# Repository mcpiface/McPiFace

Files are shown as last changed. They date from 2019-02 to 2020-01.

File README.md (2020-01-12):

# McPiFace

A Simple front panel for a raspberry pi to allow for blade style rack mounting.





## Version 1.1

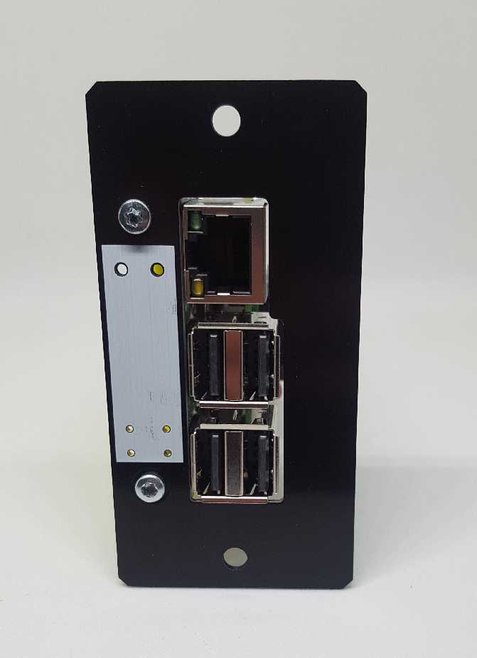
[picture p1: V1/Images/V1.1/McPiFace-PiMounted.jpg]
Pi Mounted


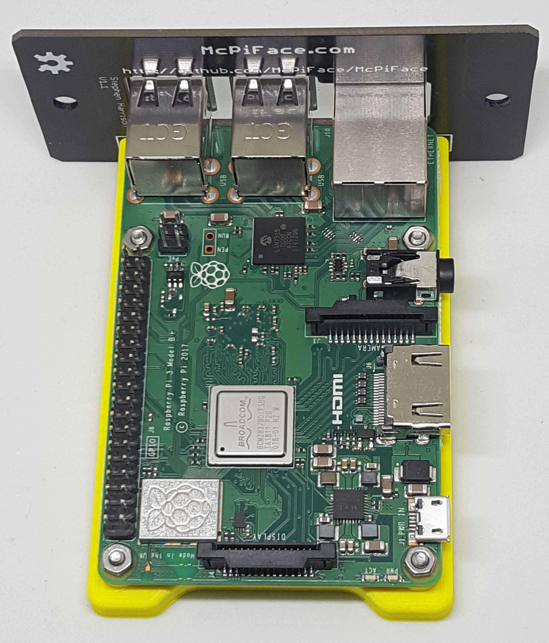
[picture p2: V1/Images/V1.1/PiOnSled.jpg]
Pi On Sled


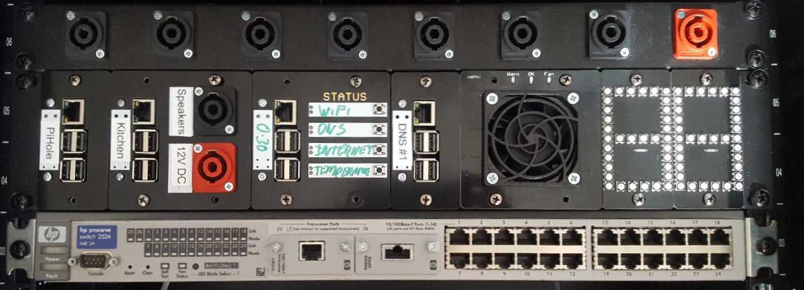
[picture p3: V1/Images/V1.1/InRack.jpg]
Various McPiFace's in a rack


## Connections

McPiFace has 2 LEDs (red/green) and a push button option. These can be ignored if not required.

Should you wish to use them, the examples assume the front panel connector is wired as follows: 

Black: Pin 39 GND
Red: Pin 40 (BCM 21)
Green: Pin 38 (BCM 20)
Blue (or Yellow): Pin 37 (BCM 26)

See https://pinout.xyz/ for Raspberry Pi header pinout.

## Python Code

The Examples folder contains sample Python code to interact with the LEDs and buttons.

The McPyFace.py script can be run to monitor the Pi's temperature and change the red/green LED when it gets hot, as well as shutdown or reboot the Pi when the button is pressed.

This file should be called from rc.local at startup. Instructions are given in the file to configure this and set permissions.

## Sled

To mount the raspberry Pi a 3D printable sled is available:

https://www.thingiverse.com/thing:3488157

## Rack Mount Frame

DAP Audio 2 HE Rackblende f. Modulsystem 10 Segmente MP-1 from Music Store.

* UK: https://www.dv247.com/en_GB/GBP/DAP-Audio-2-HE-Rackblende-f-Modulsystem-10-Segmente-MP-1/art-PAH0017160-000

* Germany: https://www.musicstore.de/en_US/USD/DAP-Audio-2-HE-Rackblende-f-Modulsystem-10-Segmente-MP-1/art-PAH0017160-000

## Version History

V1.0 - had Leds "hidden" in the vent grill and no button.
V1.1 - adopted common LED/button layout used across other McPiFace front panels.

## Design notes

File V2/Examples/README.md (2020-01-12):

# Example Python Scripts

The scripts in this folder are examples of how you might configure or use the LEDs and button on the McPiFace with a Raspberry Pi.

## Raspberry Pi Setup

The examples assume you've got python development environment installed on your Pi. Please follow http://raspberry.io/projects/view/reading-and-writing-from-gpio-ports-from-python/ if not.

## Connections

The samples assume the front panel connector is wired as follows: 

Black: Pin 39 GND
Red: Pin 40 (BCM 21)
Green: Pin 38 (BCM 20)
Blue (or Yellow): Pin 37 (BCM 26)

See https://pinout.xyz/ for Raspberry Pi header pinout.

## Simple.py

This example reads the button input, lights the green then red LEDs, switches off the LEDs and reads the button a second time.

## ButtonCallback.py

Demonstrates using a callback function to handle the button

## WaitForButton

Demonstrates reading the button status.

## McPiFace.py

This is the main script to run for the McPiFace LED/buttons. 

It will set the LEDs to red/green based on the Pi's temperature. Going red at 80C. Change:

pi_temperature_warning = 80

to a different value to change the LED indication.

Pressing the button will cause the Pi to shutdown. Swap the comment # over to switch between shutdown and reboot.

os.system('sudo shutdown now') # shutdown
#os.system('sudo shutdown -r now') # reboot

## Other examples:

### On Off switch from The Mag Pi Magazine 

Note the switch is wired to GPIO 21, not 26 as used by McPiFace, so you'll need to change the code.

https://www.raspberrypi.org/magpi/off-switch-raspberry-pi/

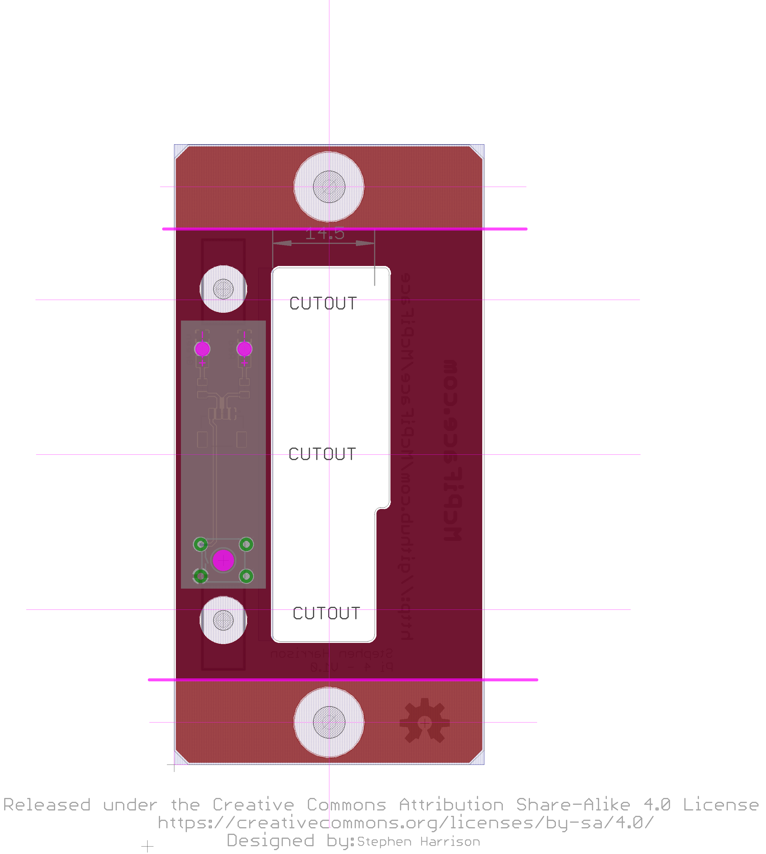
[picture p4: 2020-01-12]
V2/Images/PcbAllLayersDesign.png

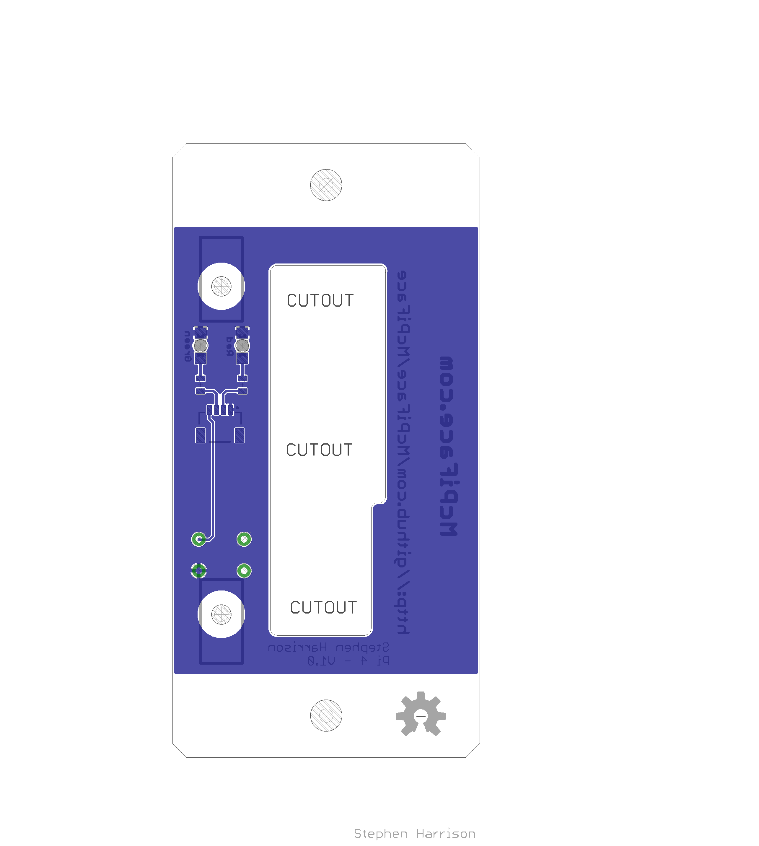
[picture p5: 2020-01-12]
V2/Images/PcbBottomDesign.png

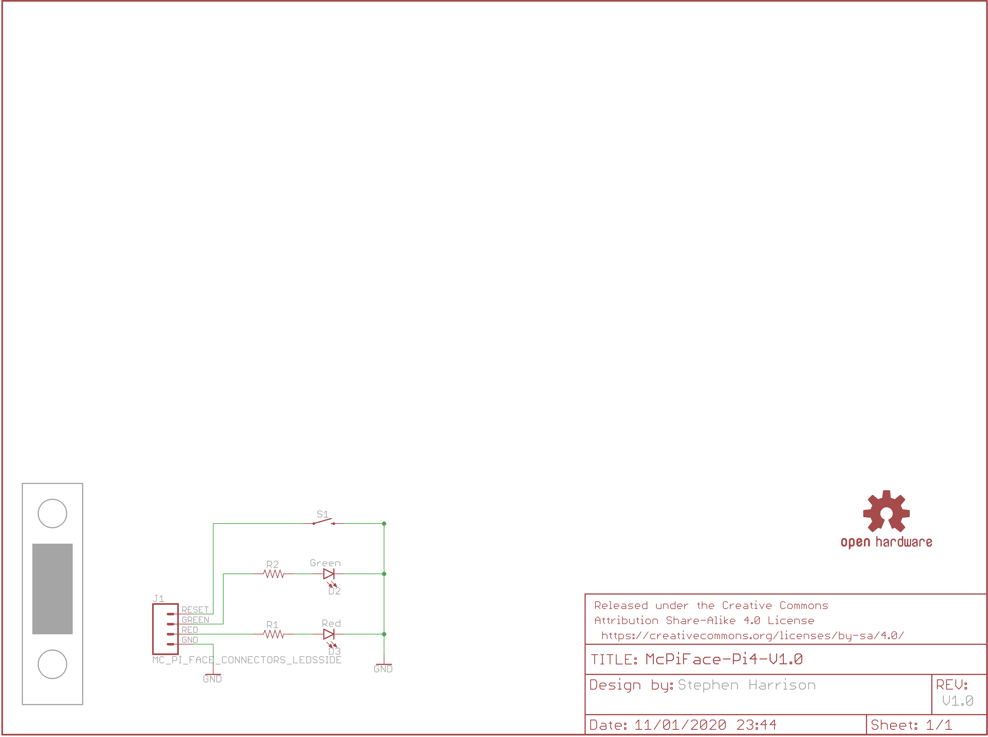
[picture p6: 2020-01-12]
V2/Images/Schematic.png

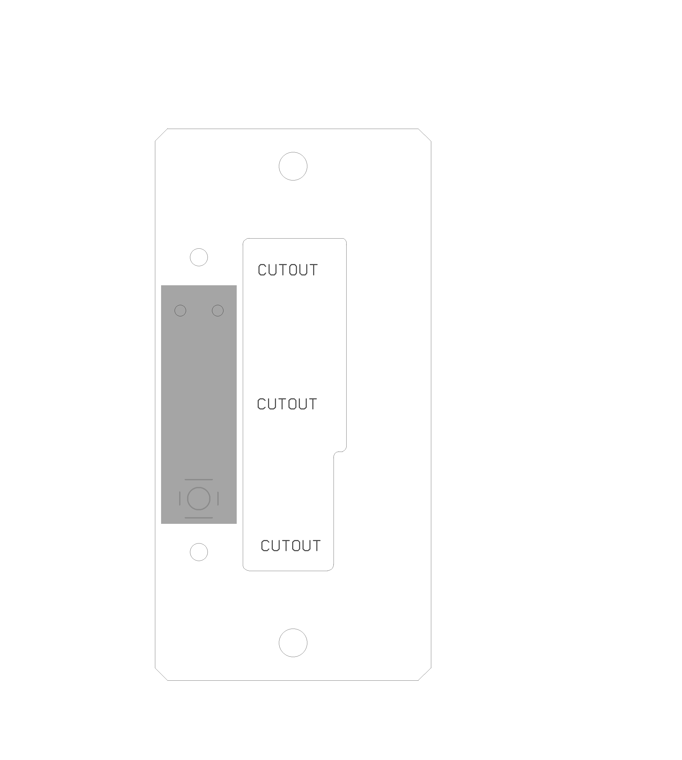
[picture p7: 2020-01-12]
V2/Images/PcbTopSilkAndValues.png

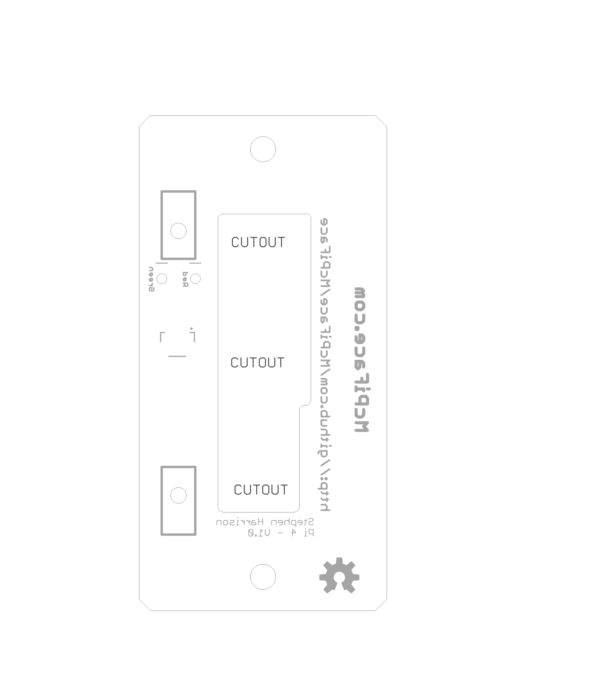
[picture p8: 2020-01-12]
V2/Images/PcbBottomSilkAndValues.png

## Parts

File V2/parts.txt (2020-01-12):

Partlist

Exported from McPiFace-Pi4-V1.0.brd at 12/01/2020 15:57

EAGLE Version 7.4.0 Copyright (c) 1988-2015 CadSoft

Assembly variant: 

Part     Value                                                        Package                                Library            Position (mm)         Orientation

D2       Green                                                        LED-1206-BOTTOM-2.0MM                  ThingySticks       (4 59)                MR90
D3       Red                                                          LED-1206-BOTTOM-2.0MM                  ThingySticks       (10 59)               MR90
J1       MC_PI_FACE_CONNECTORS_LEDSSIDE                               JST-4-SH-1.0MM-SIDE                    McPiFace           (6.8 49.8)            MR0
R1                                                                    0805                                   SparkFun-Resistors (10 53.4)             MR90
R2                                                                    0805                                   SparkFun-Resistors (4 53.4)              MR90
S1       MOMENTARY-SWITCH-SPSTTACKTILE_SWITCH_PTH_6.0MM_NO_TOP_RESIST TACTILE_SWITCH_PTH_6.0MM_NO_TOP_RESIST ThingySticks       (7 29)                R0

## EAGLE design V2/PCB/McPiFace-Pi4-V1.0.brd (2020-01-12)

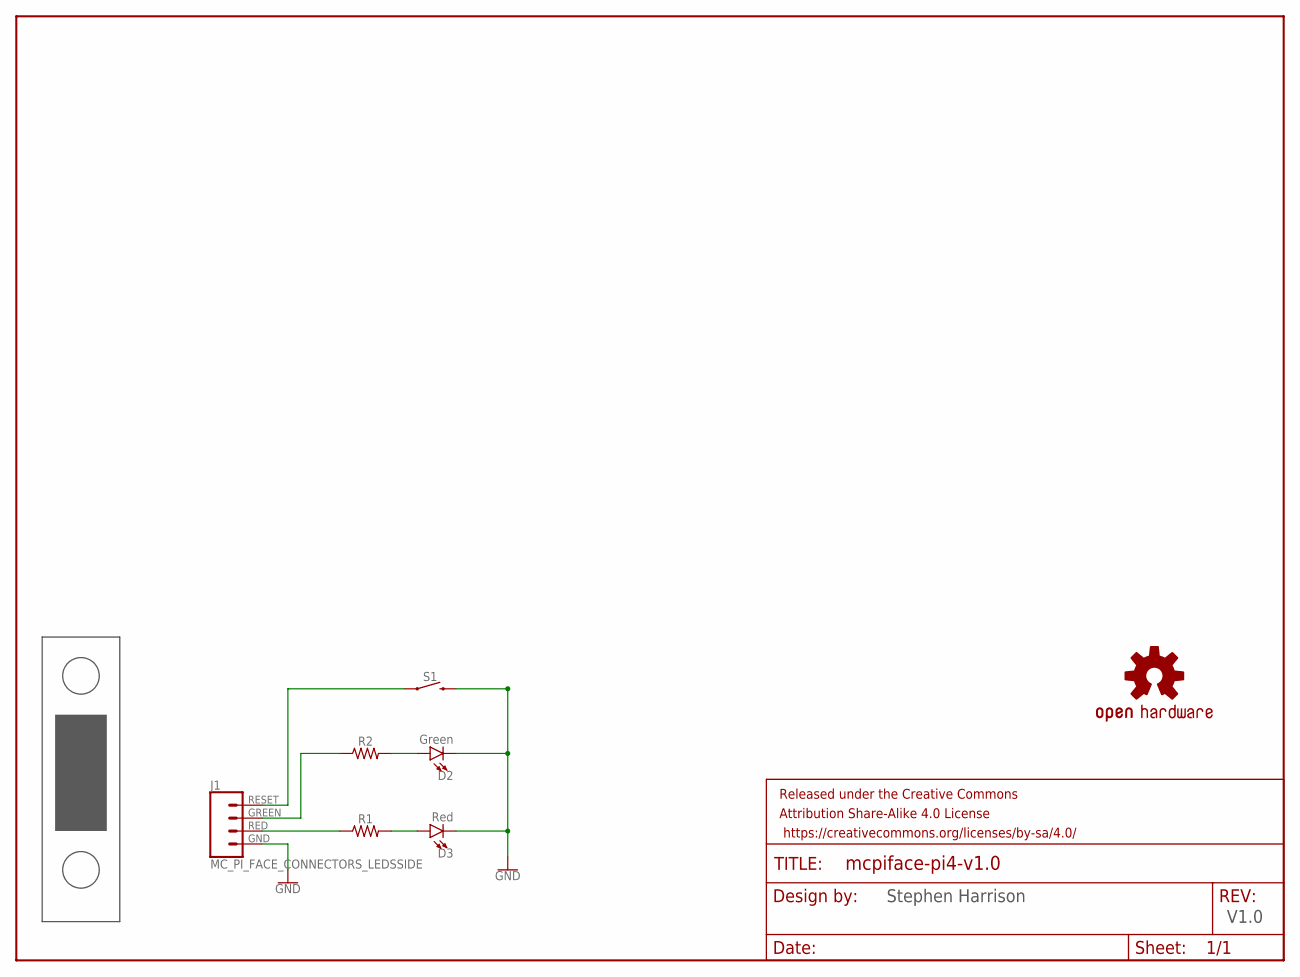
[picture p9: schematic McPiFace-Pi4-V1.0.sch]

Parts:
D2: Green; LED-1206-BOTTOM-2.0MM
D3: Red; LED-1206-BOTTOM-2.0MM
FRAME1: FRAME-LETTER; CREATIVE_COMMONS
J1: MC_PI_FACE_CONNECTORS_LEDSSIDE; JST-4-SH-1.0MM-SIDE
LOGO1: OSHW-LOGOL; OSHW-LOGO-L
R1, R2: 0805
S1: MOMENTARY-SWITCH-SPSTTACKTILE_SWITCH_PTH_6.0MM_NO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; TACTILE_SWITCH_PTH_6.0MM_NO_TOP_RESIST
U$1: MC_PI_4_FACE_PANEL; MC_PI_4_FACE

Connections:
GND: D2.C, D3.C, J1.GND, S1.3 (2)
unnamed: D2.A, R2.2
unnamed: D3.A, R1.2
unnamed: J1.RED, R1.1
unnamed: J1.GREEN, R2.1
unnamed: J1.RESET, S1.1

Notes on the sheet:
Stephen Harrison
V1.0

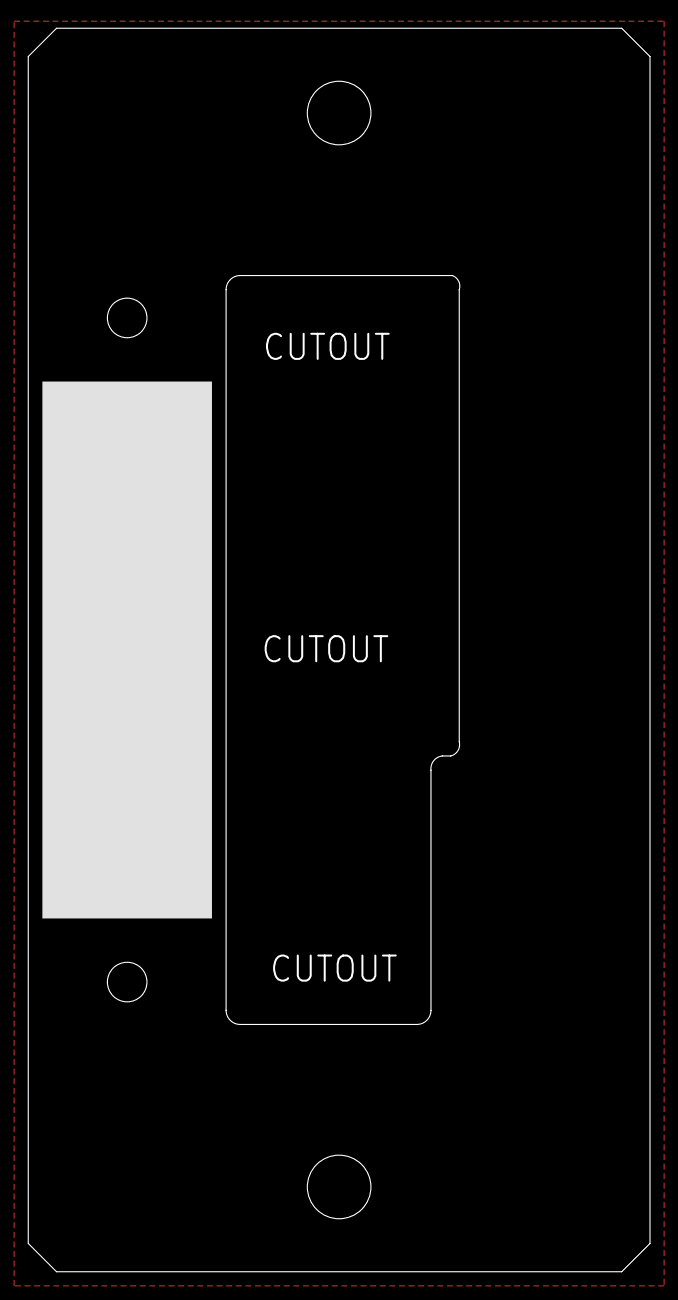
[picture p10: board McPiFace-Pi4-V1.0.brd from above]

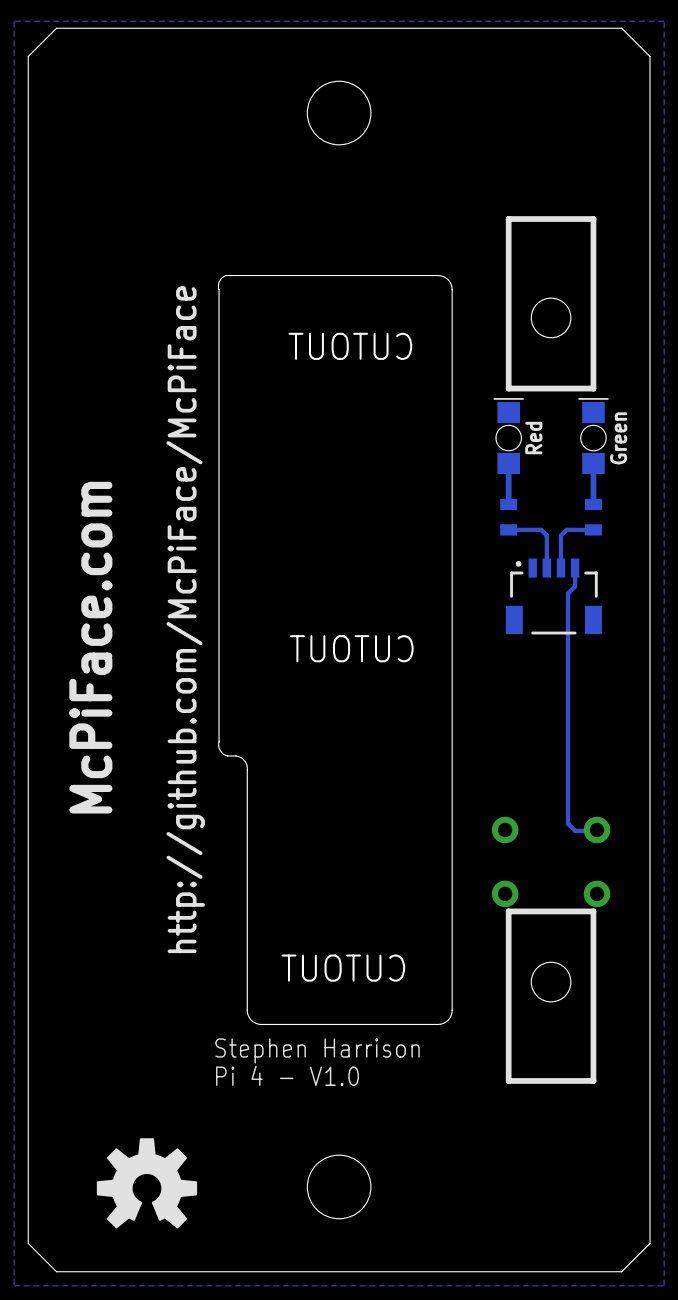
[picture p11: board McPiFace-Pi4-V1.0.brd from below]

Board: 2 copper layers, 44.0 x 88.0 mm, 9 parts (6 on the bottom side), 6 nets.

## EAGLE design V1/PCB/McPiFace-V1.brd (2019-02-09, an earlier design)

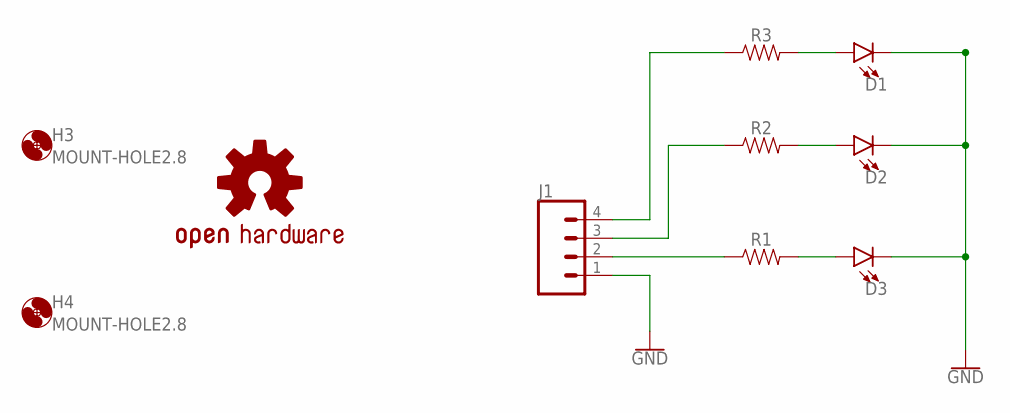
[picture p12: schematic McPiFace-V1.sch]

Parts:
D1, D2, D3: LED1206-BOTTOM-1.6MM; LED-1206-BOTTOM-1.6MM
H3, H4: MOUNT-HOLE2.8; 2,8
J1: CONN_04SMD2; 1X04_1MM_RA
LOGO1: OSHW-LOGOL; OSHW-LOGO-L
R1, R2, R3: 1206

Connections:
GND: D1.C, D2.C, D3.C, J1.1
unnamed: D1.A, R3.2
unnamed: D2.A, R2.2
unnamed: D3.A, R1.2
unnamed: J1.2, R1.1
unnamed: J1.3, R2.1
unnamed: J1.4, R3.1

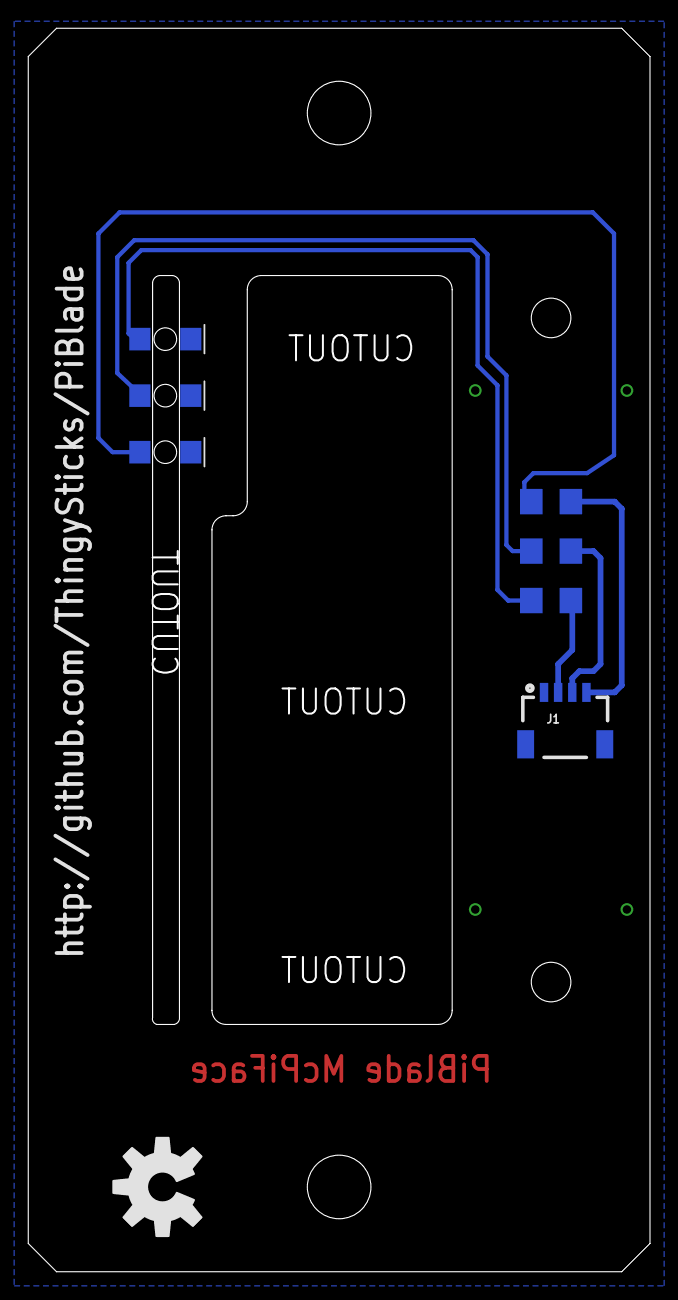
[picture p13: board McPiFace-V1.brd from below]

Board: 2 copper layers, 44.0 x 88.0 mm, 10 parts (8 on the bottom side), 7 nets.

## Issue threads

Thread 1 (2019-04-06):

Eagle Library

65816, 2019-04-06:
Is it possible to release the Eagle Library? I need to move the mounting holes further apart to fit my case (https://www.middleatlantic.com/products/accessories/connector-panels/ucp-series-modular-panel-system/ucp-ch.aspx). The holes measure 71.7mm apart and I need to be probably 76.3mm apart.

Thank you.

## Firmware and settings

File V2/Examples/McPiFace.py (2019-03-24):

#!/usr/bin/python

# This example shows how to use the McPiFace front panel
# to show a Pi temperature indicator (red/green -> hot/cold)
# and to use the button to shutdown the Pi.

# To install into rc.local and run in the background use:
# $ sudo su
# echo "~pi/McPiFace/V1/Examples/McPiFace.py &" >> /etc/rc.local

# Note: Check your rc.local file to ensure the exit 0 line is after the above McPiFace.py launcher
# Give appropriate permissions
# chmod +x /home/pi/McPiFace/V1/Examples/McPiFace.py
#
# If a library / module not globally installed try:
# sudo -H -u pi /usr/bin/python3 /home/pi/McPiFace/V1/Examples/McPiFace.py


import RPi.GPIO as GPIO
import time
import os

print 'Starting McPiFace front panel monitor'

GPIO.setmode(GPIO.BCM)
GPIO.setwarnings(False)

GreenLedGpio = 20
RedLedGpio = 21
ButtonGpio = 26

# Warning temperature - when the LED goes red.
# Raspbian set to 80C to show the temperature warning.
pi_temperature_warning = 80
keep_running = True

# These are our GPIO 
GPIO.setup(GreenLedGpio,GPIO.OUT)
GPIO.setup(RedLedGpio,GPIO.OUT)
GPIO.setup(ButtonGpio,GPIO.IN, pull_up_down=GPIO.PUD_UP)

def button_pressed_callback(self):
    print 'Button Pressed! Shutting down. BYE!'
    GPIO.output(GreenLedGpio,GPIO.LOW)
    GPIO.output(RedLedGpio,GPIO.LOW)
    os.system('sudo shutdown now') # shutdown
    #os.system('sudo shutdown -r now') # reboot
    keep_running = False

def read_pi_temperature():
    temperature = os.popen("vcgencmd measure_temp").readline()
    temperature = temperature.replace("temp=","")
    temperature = temperature.replace("'C","")
    return float(temperature)

def check_pi_temperature():
    #print 'Checking Pi Temperature'
    temperature = read_pi_temperature()
    #print 'Pi Temperature {}'.format(temperature)
    if temperature > pi_temperature_warning:
        GPIO.output(RedLedGpio,GPIO.HIGH)
        GPIO.output(GreenLedGpio,GPIO.LOW)
    else:
        GPIO.output(RedLedGpio,GPIO.LOW)
        GPIO.output(GreenLedGpio,GPIO.HIGH)

# Both LEDs on when starting up
GPIO.output(RedLedGpio,GPIO.HIGH)
GPIO.output(GreenLedGpio,GPIO.HIGH)
time.sleep(1)	

# Add event handling for the button
GPIO.add_event_detect(ButtonGpio, GPIO.FALLING)
GPIO.add_event_callback(ButtonGpio, button_pressed_callback)

# Loop forever monitoring the Pi.
while keep_running:
    check_pi_temperature()
    # Delay for a second between checks.
    time.sleep(1)	

# Clean up and exit when keep_running is reset.
GPIO.cleanup()

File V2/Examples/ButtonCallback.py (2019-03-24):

import RPi.GPIO as GPIO
import time

GPIO.setmode(GPIO.BCM)
GPIO.setwarnings(False)

GPIO.setup(20,GPIO.OUT)
GPIO.setup(21,GPIO.OUT)
GPIO.setup(26,GPIO.IN, pull_up_down=GPIO.PUD_UP)

def button_pressed_callback(self):
    print 'Button Pressed!'

    # Change to Green LED to indicate the button was pressed
    print "GREEN LED on"
    GPIO.output(20,GPIO.HIGH)
    GPIO.output(21,GPIO.LOW)
    time.sleep(2)
    # And go back to red.
    print "RED LED on"
    GPIO.output(20,GPIO.LOW)
    GPIO.output(21,GPIO.HIGH)


# Add event handling for the button
GPIO.add_event_detect(26, GPIO.FALLING)
GPIO.add_event_callback(26, button_pressed_callback)

# Red LED on whilst we wait for the button to be pressed.
print "RED LED on"
GPIO.output(21,GPIO.HIGH)
GPIO.output(20,GPIO.LOW)

# Sleep whilst we wait for the button to be pressed.
time.sleep(60)	

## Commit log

2019-02-09 V1.1 of McPiFace front panel for Rasberry Pi.
    [McPiFace-V1.brd, McPiFace-V1.sch]
2019-03-24 Adding V1.1 PCB.
    Uses common layout for LEDs, removed vent hole.
    [McPiFace-V1.1.brd, McPiFace-V1.1.sch]
2019-03-24 Added Sled and frame details.
2019-03-24 Updated wire color coding
2020-01-12 Added V2 for the Pi 4.
    [McPiFace-Pi4-V1.0.brd, McPiFace-Pi4-V1.0.sch]
2020-01-12 LED wiring label

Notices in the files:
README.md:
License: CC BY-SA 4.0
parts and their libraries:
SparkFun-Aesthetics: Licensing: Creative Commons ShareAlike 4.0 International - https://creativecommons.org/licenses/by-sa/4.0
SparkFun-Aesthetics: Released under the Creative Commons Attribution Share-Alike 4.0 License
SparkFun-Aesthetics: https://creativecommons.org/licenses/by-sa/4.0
